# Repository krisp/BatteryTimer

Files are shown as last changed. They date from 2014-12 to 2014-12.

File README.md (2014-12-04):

<pre>
BatteryTimer
============

Arduino Micro-based programmable relay switch with voltage sensing.

Includes serial CLI support for changing initial parameters to user-defined settings.

Theory of operation:
  At initial power up, default settings are saved to EEPROM. Subsequent reboots will 
  read these values. Relay is turned off unless voltage is above VOLTAGE_ON. Initially,
  the firmware remains in a fully on initial state until PD_WAIT seconds elapse. Data 
  received via the CLI resets this timer. After PD_WAIT seconds, the board goes into 
  full powerdown and wakes up every second to sense the input voltage. If the 
  voltage is sensed to be greater than or equal to VOLTAGE_ON, the relay is engaged 
  and powerdown mode is disabled. Once the voltage drops below VOLTAGE_ON, the relay 
  will remain engaged until OFF_WAIT seconds elapse. Should the voltage drop below
  VOLTAGE_LOW at any time, the relay will immediately be disengaged and powerdown mode 
  will be activated.
  
Parameters:
  VOLTAGE_ON  : voltage (float) at which the relay engages. Default: 13.2
  VOLTAGE_LOW : voltage (float) at which the relay is immediately disengaged and 
                powerdown mode activated. Default: 10.8
  OFF_WAIT    : time in seconds for the relay to remain engaged after voltage drops 
                below VOLTAGE_ON. Default: 120 (2 minutes)
  PD_WAIT     : time in seconds to wait initially before entering powerdown mode. 
                This allows the user to connect via CLI before USB is disabled.
				Default: 45 seconds
  VDROP_DETECT: Flag to enable voltage drop detection to reset delay timer (1 or 0)
  VDROP_PCT   : Multiplied by median voltage and then compared to current voltage, 
                if voltage is less it will reset the timer (in-use detect). Default
				value is 0.99 (which is 1% drop or 0.115v at 11.5v)
  
Power consumption:
  Using Arduino Micro (atmega32u4) boards acquired from China via Ebay (with power LED 
  removed), this project has been measured at 240 microamps current draw while in 
  powerdown. Full on current draw with relay engaged is ~70mA, full on current draw with 
  relay open is ~32mA. 

Using the CLI:
  Connect the Arduino Micro board via USB and establish a serial connection at 9600bps 
  within PD_WAIT. Press enter to activate the CLI and reset the PD_WAIT timer. Type
  help for a list of commands and their use. Note that changes to parameters are not
  saved until the "save" command is issued.
  
Voltage drop detection:
  The current voltage is added to an array used to compute the running median voltage
  when the system is in delayed off state. The median voltage is multiplied by VDROP_PCT 
  and compared to the current voltage reading. If the current voltage reading is less 
  than VDROP_PCT*median_voltage, the off timer is reset and the controlled device will
  remain powered on for another OFF_WAIT seconds.
</pre>

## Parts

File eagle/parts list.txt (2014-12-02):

mouser parts

K1 =  655-RTD34012 		$1.90
T1 =  863-MMBT4401LT3G 		$0.11
D1 =  625-RS1A-E3/5AT		$0.10
R1  =  660-RK73H2BTTD1001F 	$0.10
R2 =  660-RK73H2ATTD2003F 	$0.10
R3 =  660-RK73H2ATTD1003F	$0.10

Board 3x = $4.35 = 		$1.45
Arduino micro from china	$5.69
                                =====
				$9.44

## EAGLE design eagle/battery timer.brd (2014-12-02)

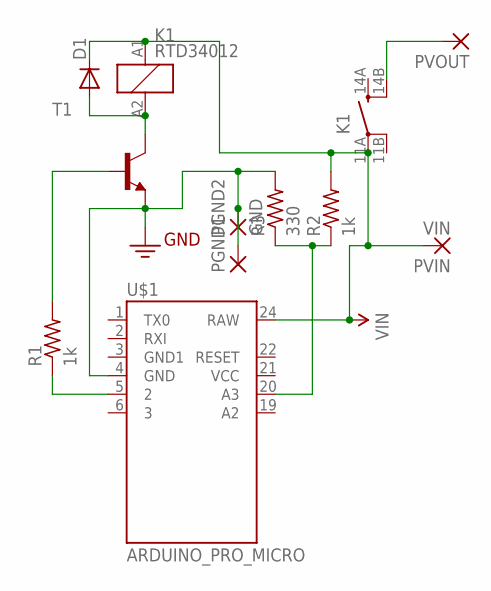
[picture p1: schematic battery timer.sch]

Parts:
D1: DIODE-DO-214AC; DO-214AC
K1: RTD34012; RT-N/O16A5
PGND1: SMD5; SMD2,54-5,08
PGND2: GND; SMD2,54-5,08
PVIN: VIN; SMD2,54-5,08
PVOUT: SMD5; SMD2,54-5,08
R1, R2: 1k; R1206
R3: 330; R1206
T1: MMBT4401LT1-NPN-SOT23-BEC; SOT23-BEC
U$1: ARDUINO_PRO_MICRO

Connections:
3.3V: PGND1.1, PGND2.1, R3.2, T1.E, U$1.4 (GND)
unnamed: R2.1, R3.1, U$1.20 (A3)
unnamed: R1.1, U$1.5 (2)
unnamed: D1.A, K1.A2 (2), T1.C
unnamed: R1.2, T1.B
PVOUT: K1.14B (SB), PVOUT.1
VIN: D1.C, K1.11A (PA), K1.A1 (1), PVIN.1, R2.2, U$1.24 (RAW)

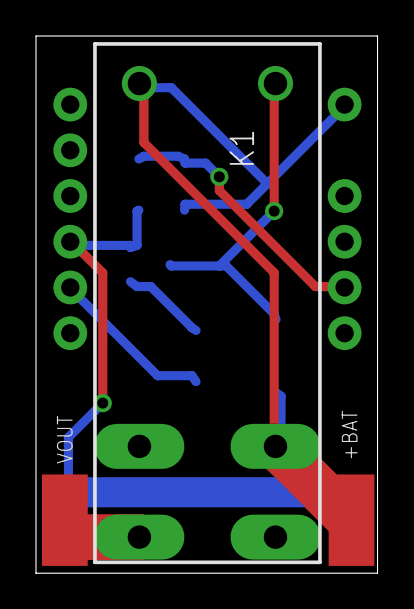
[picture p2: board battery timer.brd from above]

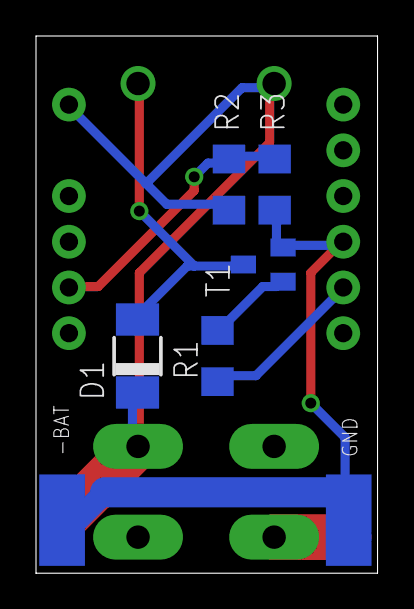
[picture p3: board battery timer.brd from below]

Board: 2 copper layers, 19.0 x 29.8 mm, 11 parts (7 on the bottom side), 7 nets.

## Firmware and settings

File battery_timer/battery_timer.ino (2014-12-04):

#if 1 // fix arduino ide bug
__asm volatile ("nop");
#endif

// Battery Timer sketch for Arduino Micro/Battery Timer PCB (c) 2014 David McKenzie 
#define DEBUG // status on serial console (~3kb)
#define CLI   // include FreakLabs CLI support

#include "LowPower.h"
#include <avr/power.h>
#include <EEPROM.h>
#include "RunningMedian.h"
#ifdef CLI
#include "Cmd.h"
#endif

struct _params_t
{
  int   CHECK;
  int   OFF_WAIT;
  int   PD_WAIT;
  int   VDIV_CONST;
  int   VDROP_DETECT;
  float VDROP_PCT;
  float VOLTAGE_LOW;
  float VOLTAGE_ON;
} params = {82, 120, 45, 3, 1, 0.99, 10.8, 13.2}; // default values, changing the check byte will reset saved settings

const int VOLTAGE_PIN  = A3; // voltage divider is connected here
const int RELAY_PIN    = 2;  // relay driver transistor base is connected here
const int EEPROM_START = 8;  // start address in eeprom, changing this will reset saved settings

float volts = 0.0; // voltage now global so it is accessable from cli

RunningMedian voltmedian = RunningMedian(9); // odd size is best

// states
bool relayState = false;
bool powerDown = true;
bool delaySwitch = false;
bool initialState = true;

unsigned long time = 0; // we can use millis because we only care about it when not in low power mode
unsigned long pd_time = 0; // this allows us reset initial mode by PD_WAIT when CLI is active

void setup()
{
// check for params in eeprom
  loadParams();
#ifdef CLI
  cmdInit(9600);
  cmdAdd("help", help);
  cmdAdd("status", bstatus);
  cmdAdd("list", list);
  cmdAdd("set", set);  
  cmdAdd("save", save);
  cmdAdd("sleep", sleep);
#elif defined(DEBUG)
  Serial.begin(9600);
#endif
  pinMode(RELAY_PIN, OUTPUT);
  digitalWrite(RELAY_PIN, LOW); // make sure relay is off state
  power_spi_disable();
  power_twi_disable();
}

void loop()
{
#ifdef DEBUG
  unsigned long nowm = micros();
#endif
  unsigned long now = millis();

  if(powerDown && !relayState && !initialState) {
    // disable usb
    power_usb_disable();
    LowPower.powerDown(SLEEP_1S, ADC_OFF, BOD_ON);
  }  

  // read the analog pin and convert to volts
  volts = ((float)(analogRead(VOLTAGE_PIN) * 5) / 1024.0) * params.VDIV_CONST;
  voltmedian.add(volts);
  
  if(delaySwitch && relayState) {
    // check for a voltage drop less than VDROP_PCT*median and reset the delay timer (in-use detection)
    if(params.VDROP_DETECT) {
      if(volts < (params.VDROP_PCT*voltmedian.getMedian())) {
        time = now; 
#ifdef DEBUG
        Serial.println("Voltage drop detected, resetting timer");
#endif
      }
    }
    // check if delayed off has expired    
    if(now > (time + (1000 * (unsigned long)params.OFF_WAIT))) {
      // shut that whole thing down
      relayOff();
    }    
  }
  
  if(volts >= params.VOLTAGE_ON) { 
    if(!relayState)  // charging system is on, relay on
      relayOn();
    if(delaySwitch)  // clear delay switch 
      delaySwitch = false;
  } else if(volts >= params.VOLTAGE_LOW && volts < params.VOLTAGE_ON) {
    // charging system off, check if relay is on and start the timer if it hasn't already been started.
    if(relayState && !delaySwitch) {  
      time = now;
      delaySwitch = true;
    }
  } else if(volts < params.VOLTAGE_LOW) {
    // low voltage, turn the relay off now
    relayOff();
  }

  if(initialState && (now - pd_time > (1000 * (unsigned long)params.PD_WAIT)))
  {
    initialState = false;
    if(!relayState)
      powerDown = true;
  }

  if(!powerDown || initialState) // wait for 500ms if we aren't powering down
  {
#ifdef CLI
    if(Serial.available()) {
      // CLI is active, reset pd_time to now to inhibit powerdown by another PD_WAIT
      pd_time = now;
    }
    cmdPoll();
#endif
#ifdef DEBUG
    printStatus(nowm, volts);
#endif 
    delay(500);
  }
}

void relayOn()
{
  digitalWrite(RELAY_PIN, HIGH);
  powerDown = false;
  power_usb_enable();; // turn usb back on in case we need to reprogram
  relayState = true;
  delaySwitch = false; // if we were in a powerdown delay we should clear it 
}

void relayOff()
{
  digitalWrite(RELAY_PIN, LOW);
  relayState = false; 
  delaySwitch = false;
  time = 0;
  powerDown = true; 
}


#if defined(DEBUG) || defined(CLI)
void printStatus(unsigned long now, float v)
{
  unsigned long n = micros();
  char buf1[8];
  char buf2[128];
  dtostrf(v, 4, 2, buf1);
  snprintf(buf2, sizeof(buf2), "%lu %lu relay: %d, delay: %d, i: %d, pD: %d, V: %s V(m): ",
              now, n-now, relayState, delaySwitch, initialState, powerDown, buf1);
  Serial.print(buf2);
  Serial.println(voltmedian.getMedian());  
}
#endif

void loadParams()
{
  // load params from eeprom
  if(EEPROM.read(EEPROM_START) == params.CHECK) { // check for our CHECK byte is the same as the default
    for (unsigned int i=0; i<sizeof(params); i++)
      *((char*)&params+i) = EEPROM.read(EEPROM_START + i);
  } else {
    // params are uninitialized, write the defaults to memory
    saveParams(); 
  }
}

void saveParams()
{
   for(unsigned int i=0; i<sizeof(params); i++)
     EEPROM.write(EEPROM_START+i,*((char*)&params+i));
}

#ifdef CLI
void help(int argc, char **args)
{
  Serial.println("Command list:");
  Serial.println("  help                - this message");
  Serial.println("  status              - brief status");
  Serial.println("  list                - list parameters");
  Serial.println("  set <param> <value> - set parameter for this session");
  Serial.println("  save                - save parameters to eeprom");
  Serial.println("  sleep               - immediately enter powerdown mode (will end USB shell)");
}

void bstatus(int argc, char **args)
{
  printStatus(micros(),volts);
}

void list(int argc, char **args)
{
  char buf[100];
  char v1[8];
  char v2[8];
  char v3[8];
  dtostrf(params.VOLTAGE_LOW, 4, 2, v1);
  dtostrf(params.VOLTAGE_ON, 4, 2, v2);
  dtostrf(params.VDROP_PCT, 4, 3, v3);
  snprintf(buf, sizeof(buf), "OFF_WAIT: %d\n\rPD_WAIT: %d\n\rVOLTAGE_LOW: %s\n\rVOLTAGE_ON: %s\n\rVDROP_DETECT: %d\n\rVDROP_PCT: %s\n\r",
            params.OFF_WAIT, params.PD_WAIT, v1, v2, params.VDROP_DETECT, v3);
  Serial.print(buf);
}

void set(int argc, char **args)
{
  if(argc == 3) {
    char *p = args[1];
    if(!strcmp(p, "OFF_WAIT")) {
      params.OFF_WAIT = atoi(args[2]);
    } else if(!strcmp(p,"PD_WAIT")) {
      params.PD_WAIT = atoi(args[2]);
    } else if(!strcmp(p,"VOLTAGE_LOW")) {
      params.VOLTAGE_LOW = atof(args[2]);
    } else if(!strcmp(p,"VOLTAGE_ON")) {
      params.VOLTAGE_ON = atof(args[2]);
    } else if(!strcmp(p,"VDROP_PCT")) {
      params.VDROP_PCT = atof(args[2]);
    } else if(!strcmp(p,"VDROP_DETECT")) {
      params.VDROP_DETECT = atoi(args[2]);
    } else {
      Serial.println("Error: unknown parameter. Try list. Parameters are case sensitive.");  
      return;
    }
    Serial.println("Success");
  } else {
    Serial.println("Error: syntax: set <param> <value>");
  }  
}

void save(int argc, char **args)
{
  saveParams(); 
  Serial.println("Success");
}

void sleep(int argc, char **args)
{
  Serial.println("Setting sleep mode, goodbye!");
  powerDown = true;
  initialState = false;
}
#endif

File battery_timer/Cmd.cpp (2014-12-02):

/*******************************************************************
    Copyright (C) 2009 FreakLabs
    All rights reserved.

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
    1. Redistributions of source code must retain the above copyright
       notice, this list of conditions and the following disclaimer.
    2. Redistributions in binary form must reproduce the above copyright
       notice, this list of conditions and the following disclaimer in the
       documentation and/or other materials provided with the distribution.
    3. Neither the name of the the copyright holder nor the names of its contributors
       may be used to endorse or promote products derived from this software
       without specific prior written permission.

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
    Originally written by Christopher Wang aka Akiba.
    Please post support questions to the FreakLabs forum.
*/

#include <avr/pgmspace.h>
#include "Arduino.h"
#include "HardwareSerial.h"
#include "Cmd.h"

// command line message buffer and pointer
static uint8_t msg[MAX_MSG_SIZE];
static uint8_t *msg_ptr;

// linked list for command table
static cmd_t *cmd_tbl_list, *cmd_tbl;

// text strings for command prompt
const char cmd_banner[] = "++++++++ Battery Timer 1.1 (c) 2014 DPM ++++++++";
const char cmd_prompt[] = "$ ";
const char cmd_unrecog[] = "Error: Command not recognized. Try help.";

/**************************************************************************/
/*
    Generate the main command prompt
*/
/**************************************************************************/
void cmd_display()
{
    char buf[50];

    Serial.println();

    strcpy(buf, cmd_banner);
    Serial.println(buf);

    strcpy(buf, cmd_prompt);
    Serial.print(buf);
}

/**************************************************************************/
/*
    Parse the command line. This function tokenizes the command input, then
    searches for the command table entry associated with the commmand. Once found,
    it will jump to the corresponding function.
*/
/**************************************************************************/
void cmd_parse(char *cmd)
{
    uint8_t argc, i = 0;
    char *argv[30];
    char buf[50];
    cmd_t *cmd_entry;

    fflush(stdout);

    // parse the command line statement and break it up into space-delimited
    // strings. the array of strings will be saved in the argv array.
    argv[i] = strtok(cmd, " ");
    do
    {
        argv[++i] = strtok(NULL, " ");
    } while ((i < 30) && (argv[i] != NULL));
    
    // save off the number of arguments for the particular command.
    argc = i;

    // parse the command table for valid command. used argv[0] which is the
    // actual command name typed in at the prompt
    for (cmd_entry = cmd_tbl; cmd_entry != NULL; cmd_entry = cmd_entry->next)
    {
        if (!strcmp(argv[0], cmd_entry->cmd))
        {
            cmd_entry->func(argc, argv);
            cmd_display();
            return;
        }
    }

    // command not recognized. print message and re-generate prompt.
    strcpy(buf, cmd_unrecog);
    Serial.println(buf);

    cmd_display();
}

/**************************************************************************/
/*
    This function processes the individual characters typed into the command
    prompt. It saves them off into the message buffer unless its a "backspace"
    or "enter" key. 
*/
/**************************************************************************/
void cmd_handler()
{
    char c = Serial.read();

    switch (c)
    {
    case '\r':
        // terminate the msg and reset the msg ptr. then send
        // it to the handler for processing.
        *msg_ptr = '\0';
        Serial.print("\r\n");
        cmd_parse((char *)msg);
        msg_ptr = msg;
        break;
    
    case '\b':
        // backspace 
        Serial.print(c);
        if (msg_ptr > msg)
        {
            msg_ptr--;
        }
        break;
    
    default:
        // normal character entered. add it to the buffer
        Serial.print(c);
        *msg_ptr++ = c;
        break;
    }
}

/**************************************************************************/
/*
    This function should be set inside the main loop. It needs to be called
    constantly to check if there is any available input at the command prompt.
*/
/**************************************************************************/
void cmdPoll()
{
    while (Serial.available())
    {
        cmd_handler();
    }
}

/**************************************************************************/
/*
    Initialize the command line interface. This sets the terminal speed and
    and initializes things. 
*/
/**************************************************************************/
void cmdInit(uint32_t speed)
{
    // init the msg ptr
    msg_ptr = msg;

    // init the command table
    cmd_tbl_list = NULL;

    // set the serial speed
    Serial.begin(speed);
}

/**************************************************************************/
/*
    Add a command to the command table. The commands should be added in
    at the setup() portion of the sketch. 
*/
/**************************************************************************/
void cmdAdd(const char *name, void (*func)(int argc, char **argv))
{
    // alloc memory for command struct
    cmd_tbl = (cmd_t *)malloc(sizeof(cmd_t));

    // alloc memory for command name
    char *cmd_name = (char *)malloc(strlen(name)+1);

    // copy command name
    strcpy(cmd_name, name);

    // terminate the command name
    cmd_name[strlen(name)] = '\0';

    // fill out structure
    cmd_tbl->cmd = cmd_name;
    cmd_tbl->func = func;
    cmd_tbl->next = cmd_tbl_list;
    cmd_tbl_list = cmd_tbl;
}

/**************************************************************************/
/*
    Convert a string to a number. The base must be specified, ie: "32" is a
    different value in base 10 (decimal) and base 16 (hexadecimal).
*/
/**************************************************************************/
uint32_t cmdStr2Num(char *str, uint8_t base)
{
    return strtol(str, NULL, base);
}

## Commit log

2014-12-02 Added board files and version 1.0 source
    [battery timer.brd, battery timer.sch]
2014-12-02 Move status printing into initialState delay block
    USB is off during power down, so make sure we are in the initial state
    or power down mode is off before trying to print the status.
2014-12-04 Added running median and voltage drop detection
2014-12-04 Moved around loop execution measurement and fixed string buffer overflow on param list
    [battery_timer.ino]
2014-12-04 Added VDROP_DETECT param to toggle voltage drop detect

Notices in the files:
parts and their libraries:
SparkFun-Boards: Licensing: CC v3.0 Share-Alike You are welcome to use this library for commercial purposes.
